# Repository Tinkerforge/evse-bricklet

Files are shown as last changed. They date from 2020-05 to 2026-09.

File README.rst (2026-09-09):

EVSE Bricklet
=============

This Bricklet together with the ESP32 Brick the NFC Bricklet and the
RS485 Bricklet form the hardware used in the WARP Charger.

See https://www.warp-charger.com/warp1.html for more details.

This repository contains the firmware source code and the hardware design
files. The documentation generator configs can be found at
https://github.com/Tinkerforge/generators

.. BEGIN WARP REPOSITORIES (managed block, generated from esp32-firmware/repo_overview.rst - do not edit by hand, run update_repo_overview.py instead)

WARP Repositories
-----------------

This is an overview of all repositories that make up the WARP Charger and
WARP Energy Manager ecosystem.

Please report **any** issue concerning WARP hard- or software in the
`esp32-firmware`_ repository, no matter which repository it originates from.

Software
~~~~~~~~

- `esp32-firmware`_ - Source code of the ESP32 firmware shared between all WARP Chargers and Energy Managers

Libraries used by the firmware:

- `tfjson`_ - SAX style JSON serializer and deserializer
- `tfnetwork`_ - Modbus TCP server and client implementation
- `tfocpp`_ - OCPP 1.6 implementation
- `tftools`_ - Miscellaneous tools and helpers

Remote access:

- `esp32-remote-access`_ - Source code of the my.warp-charger.com remote access server

Documentation, tools and integrations:

- `warp-charger`_ - Source code of (docs.)warp-charger.com and the printed manual, released firmwares, datasheets and documents, as well as some tools and hardware design files
- `api.warp-charger.com`_ - Serves APIs that are used by WARP Chargers to obtain relevant public information like day ahead prices
- `vislog.warp-charger.com`_ - Visualizes WARP Charger logs and EVSE debug protocols
- `dbus-warp-charger`_ - Integrates WARP Chargers into a Victron Energy Venus OS device (e.g. Cerbo GX)

WARP Charger Hardware
~~~~~~~~~~~~~~~~~~~~~~

WARP4 Charger
"""""""""""""

*Current charger generation.*

- `warp-esp32-ethernet-v2-brick`_ - Hardware design files of the WARP ESP32 Ethernet Brick 2.0
- `warp-esp32-ethernet-v2-co-bricklet`_ - Firmware source code of the WARP ESP32 Ethernet 2.0 Co Bricklet (co-processor)
- `evse-v4-bricklet`_ - Hardware design files of the EVSE 4.0 Bricklet (firmware shared with the EVSE 2.0 Bricklet)
- `nfc-bricklet`_ - Firmware source code and hardware design files of the NFC Bricklet

WARP3 Charger
"""""""""""""

- `warp-esp32-ethernet-brick`_ - Hardware design files of the WARP ESP32 Ethernet Brick
- `evse-v3-bricklet`_ - Hardware design files of the EVSE 3.0 Bricklet (firmware shared with the EVSE 2.0 Bricklet)
- `nfc-bricklet`_ - Firmware source code and hardware design files of the NFC Bricklet

WARP2 Charger
"""""""""""""

- `esp32-ethernet-brick`_ - Hardware design files of the ESP32 Ethernet Brick
- `evse-v2-bricklet`_ - Firmware source code and hardware design files of the EVSE 2.0 Bricklet
- `nfc-bricklet`_ - Firmware source code and hardware design files of the NFC Bricklet

WARP1 Charger
"""""""""""""

- `esp32-brick`_ - Hardware design files of the ESP32 Brick
- `evse-bricklet`_ - Firmware source code and hardware design files of the EVSE Bricklet
- `rs485-bricklet`_ - Firmware source code and hardware design files of the RS485 Bricklet

WARP Energy Manager Hardware
~~~~~~~~~~~~~~~~~~~~~~~~~~~~~~

WARP Energy Manager 2.0
"""""""""""""""""""""""

*Current energy manager generation.*

- `esp32-ethernet-brick`_ - Hardware design files of the ESP32 Ethernet Brick
- `warp-energy-manager-v2-bricklet`_ - Firmware source code and hardware design files of the WARP Energy Manager 2.0 Bricklet
- `warp-front-panel-bricklet`_ - Firmware source code and hardware design files of the WARP Front Panel Bricklet

WARP Energy Manager 1.0
"""""""""""""""""""""""

- `esp32-ethernet-brick`_ - Hardware design files of the ESP32 Ethernet Brick
- `warp-energy-manager-bricklet`_ - Firmware source code and hardware design files of the WARP Energy Manager Bricklet

Forked/patched projects
~~~~~~~~~~~~~~~~~~~~~~~~~

- `arduino-esp32`_
- `esp32-arduino-libs`_
- `WireGuard-ESP32-Arduino`_

.. Link targets: One definition per repository, keep in sync with the lists above.

.. _esp32-firmware: https://github.com/Tinkerforge/esp32-firmware
.. _tfjson: https://github.com/Tinkerforge/tfjson
.. _tfnetwork: https://github.com/Tinkerforge/tfnetwork
.. _tfocpp: https://github.com/Tinkerforge/tfocpp
.. _tftools: https://github.com/Tinkerforge/tftools
.. _esp32-remote-access: https://github.com/Tinkerforge/esp32-remote-access
.. _warp-charger: https://github.com/Tinkerforge/warp-charger
.. _api.warp-charger.com: https://github.com/Tinkerforge/api.warp-charger.com
.. _vislog.warp-charger.com: https://github.com/Tinkerforge/vislog.warp-charger.com
.. _dbus-warp-charger: https://github.com/Tinkerforge/dbus-warp-charger
.. _warp-esp32-ethernet-v2-brick: https://github.com/Tinkerforge/warp-esp32-ethernet-v2-brick
.. _warp-esp32-ethernet-v2-co-bricklet: https://github.com/Tinkerforge/warp-esp32-ethernet-v2-co-bricklet
.. _evse-v4-bricklet: https://github.com/Tinkerforge/evse-v4-bricklet
.. _nfc-bricklet: https://github.com/Tinkerforge/nfc-bricklet
.. _warp-esp32-ethernet-brick: https://github.com/Tinkerforge/warp-esp32-ethernet-brick
.. _evse-v3-bricklet: https://github.com/Tinkerforge/evse-v3-bricklet
.. _esp32-ethernet-brick: https://github.com/Tinkerforge/esp32-ethernet-brick
.. _evse-v2-bricklet: https://github.com/Tinkerforge/evse-v2-bricklet
.. _esp32-brick: https://github.com/Tinkerforge/esp32-brick
.. _evse-bricklet: https://github.com/Tinkerforge/evse-bricklet
.. _rs485-bricklet: https://github.com/Tinkerforge/rs485-bricklet
.. _warp-energy-manager-v2-bricklet: https://github.com/Tinkerforge/warp-energy-manager-v2-bricklet
.. _warp-front-panel-bricklet: https://github.com/Tinkerforge/warp-front-panel-bricklet
.. _warp-energy-manager-bricklet: https://github.com/Tinkerforge/warp-energy-manager-bricklet
.. _arduino-esp32: https://github.com/Tinkerforge/arduino-esp32
.. _esp32-arduino-libs: https://github.com/Tinkerforge/esp32-arduino-libs
.. _WireGuard-ESP32-Arduino: https://github.com/Tinkerforge/WireGuard-ESP32-Arduino

.. END WARP REPOSITORIES

Repository Content
------------------

software/:
 * examples/: Examples for all supported languages
 * build/: Compiled files
 * src/: Source code of firmware
 * Makefile: Makefile to build project

hardware/:
 * Contains KiCad project files and additionally schematics as PDF

datasheets/:
 * Contains datasheets for sensors and complex ICs that are used

Hardware
--------

The hardware is designed with the open source EDA Suite KiCad
(http://www.kicad.org). Before you are able to open the files,
you have to install the Tinkerforge kicad-libraries
(https://github.com/Tinkerforge/kicad-libraries). You can either clone
them directly in hardware/ or clone them in a separate folder and
symlink them into hardware/
(ln -s kicad_path/kicad-libraries project_path/hardware). After that you
can open the .pro file in hardware/ with KiCad and from there view and
modify the schematics and the PCB layout.

Software
--------

If you want to do your own Brick/Bricklet firmware development we highly
recommend that you use our build environment setup script and read the
tutorial (https://www.tinkerforge.com/en/doc/Tutorials/Tutorial_Build_Environment/Tutorial.html).

To compile the C code we recommend you to install the newest GNU Arm Embedded
Toolchain (https://launchpad.net/gcc-arm-embedded/+download).
You also need to install bricklib2 (https://github.com/Tinkerforge/bricklib2).

You can either clone it directly in software/src/ or clone it in a
separate folder and symlink it into software/src/
(ln -s bricklib_path/bricklib2 project_path/software/src/). Finally make sure to
have CMake installed (http://www.cmake.org/cmake/resources/software.html).

After that you can build the firmware by invoking make in software/.
The firmware (.zbin) can then be found in software/build/ and uploaded
with brickv (click button "Flashing" on start screen).

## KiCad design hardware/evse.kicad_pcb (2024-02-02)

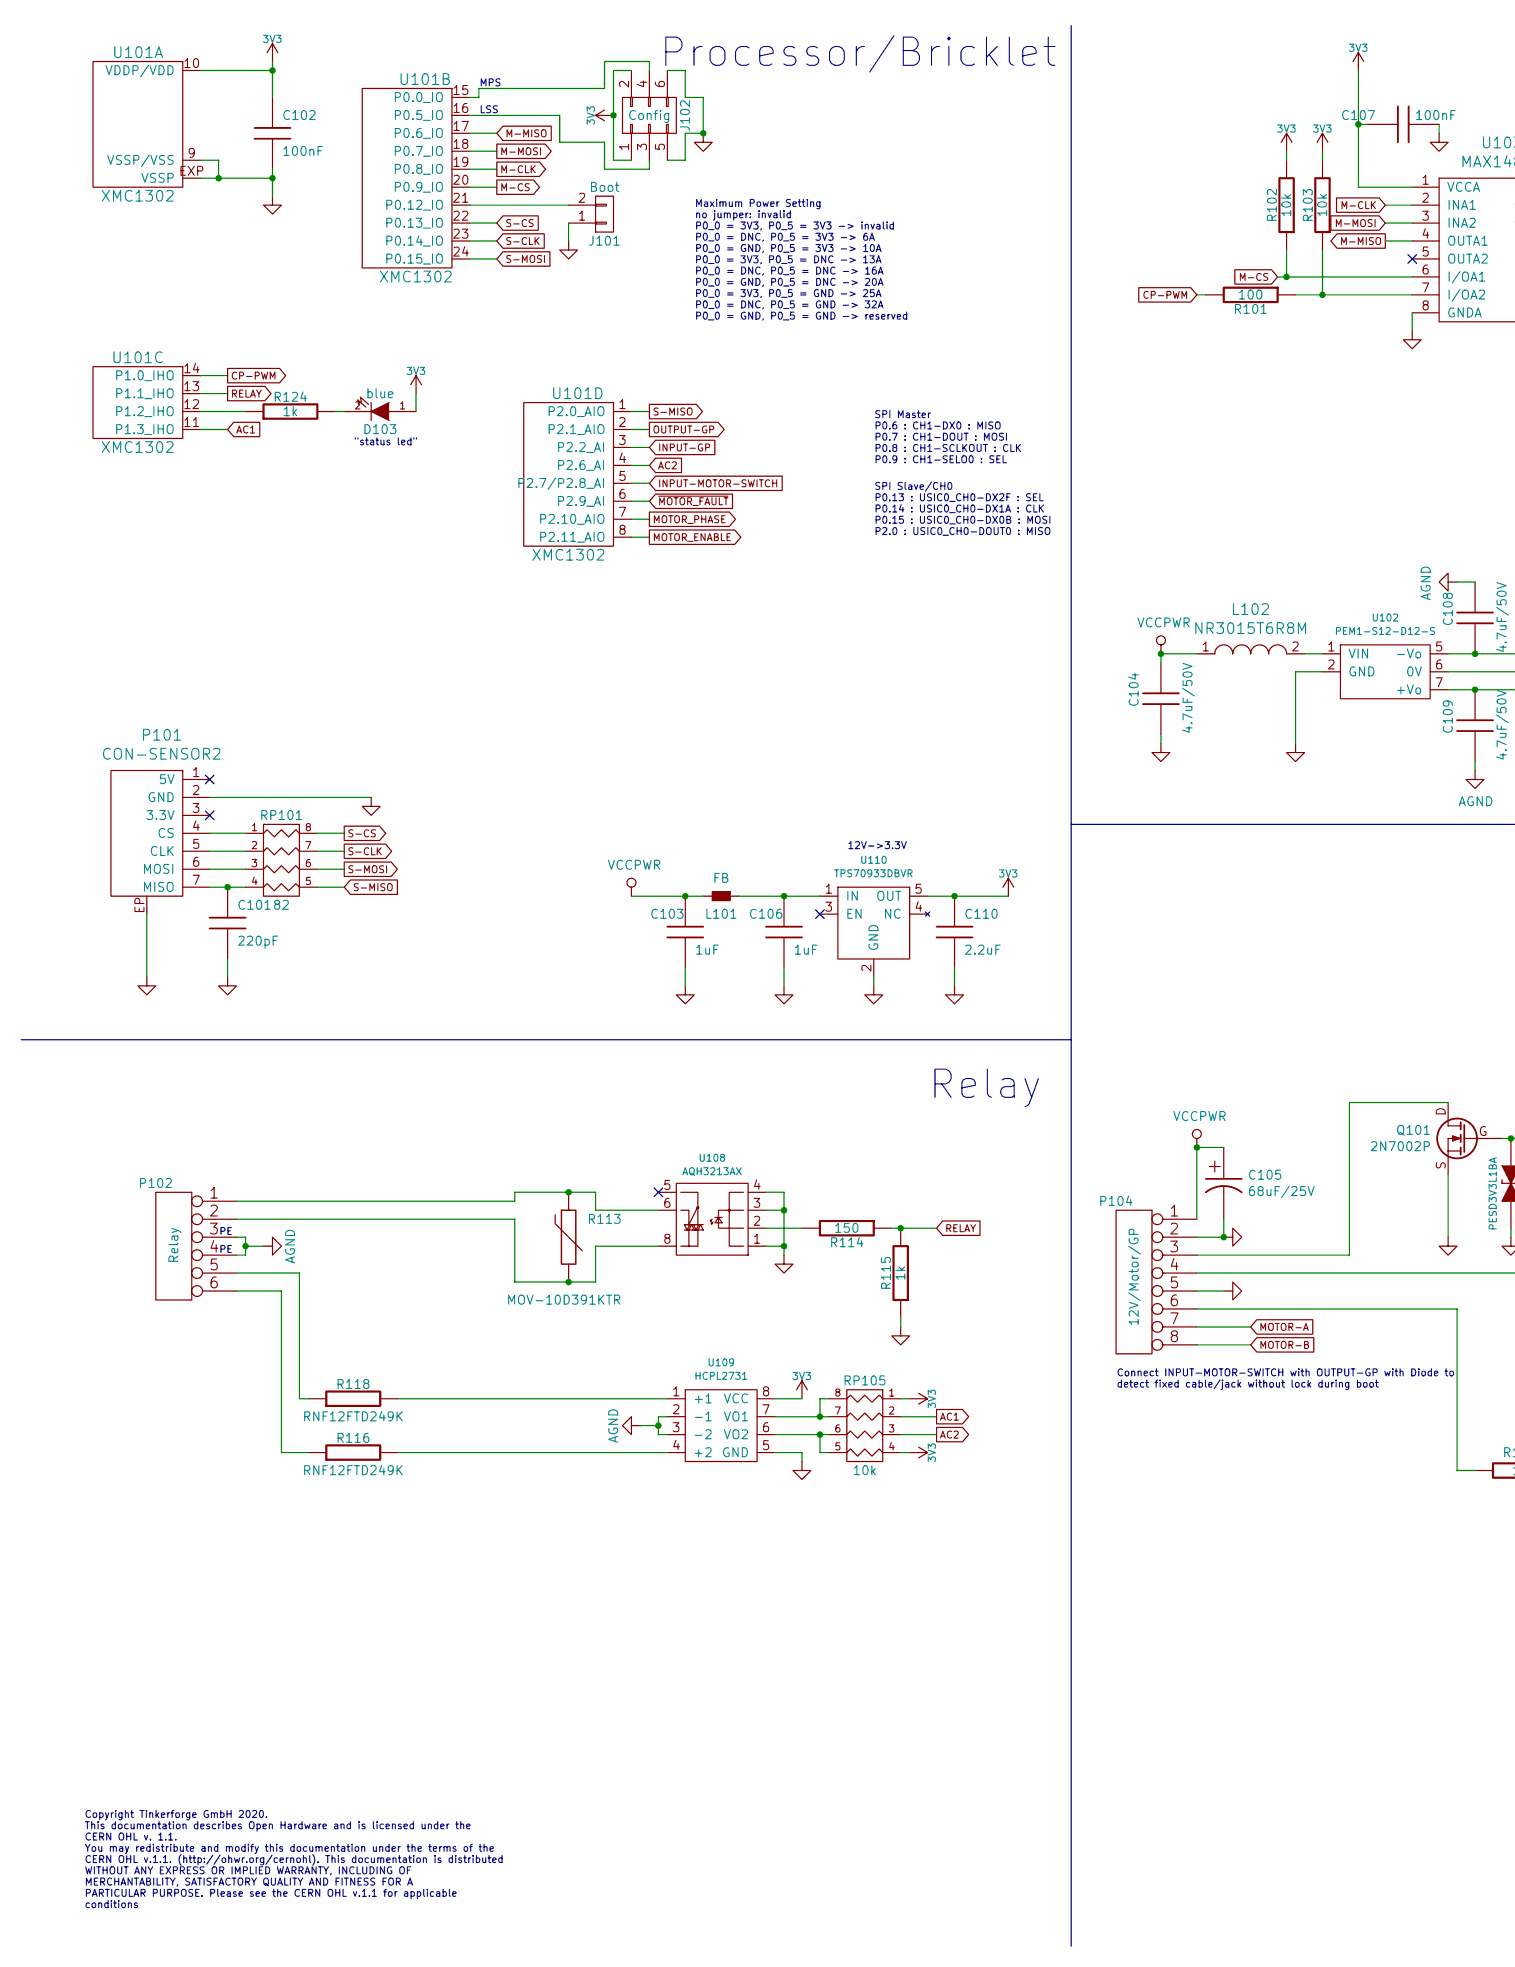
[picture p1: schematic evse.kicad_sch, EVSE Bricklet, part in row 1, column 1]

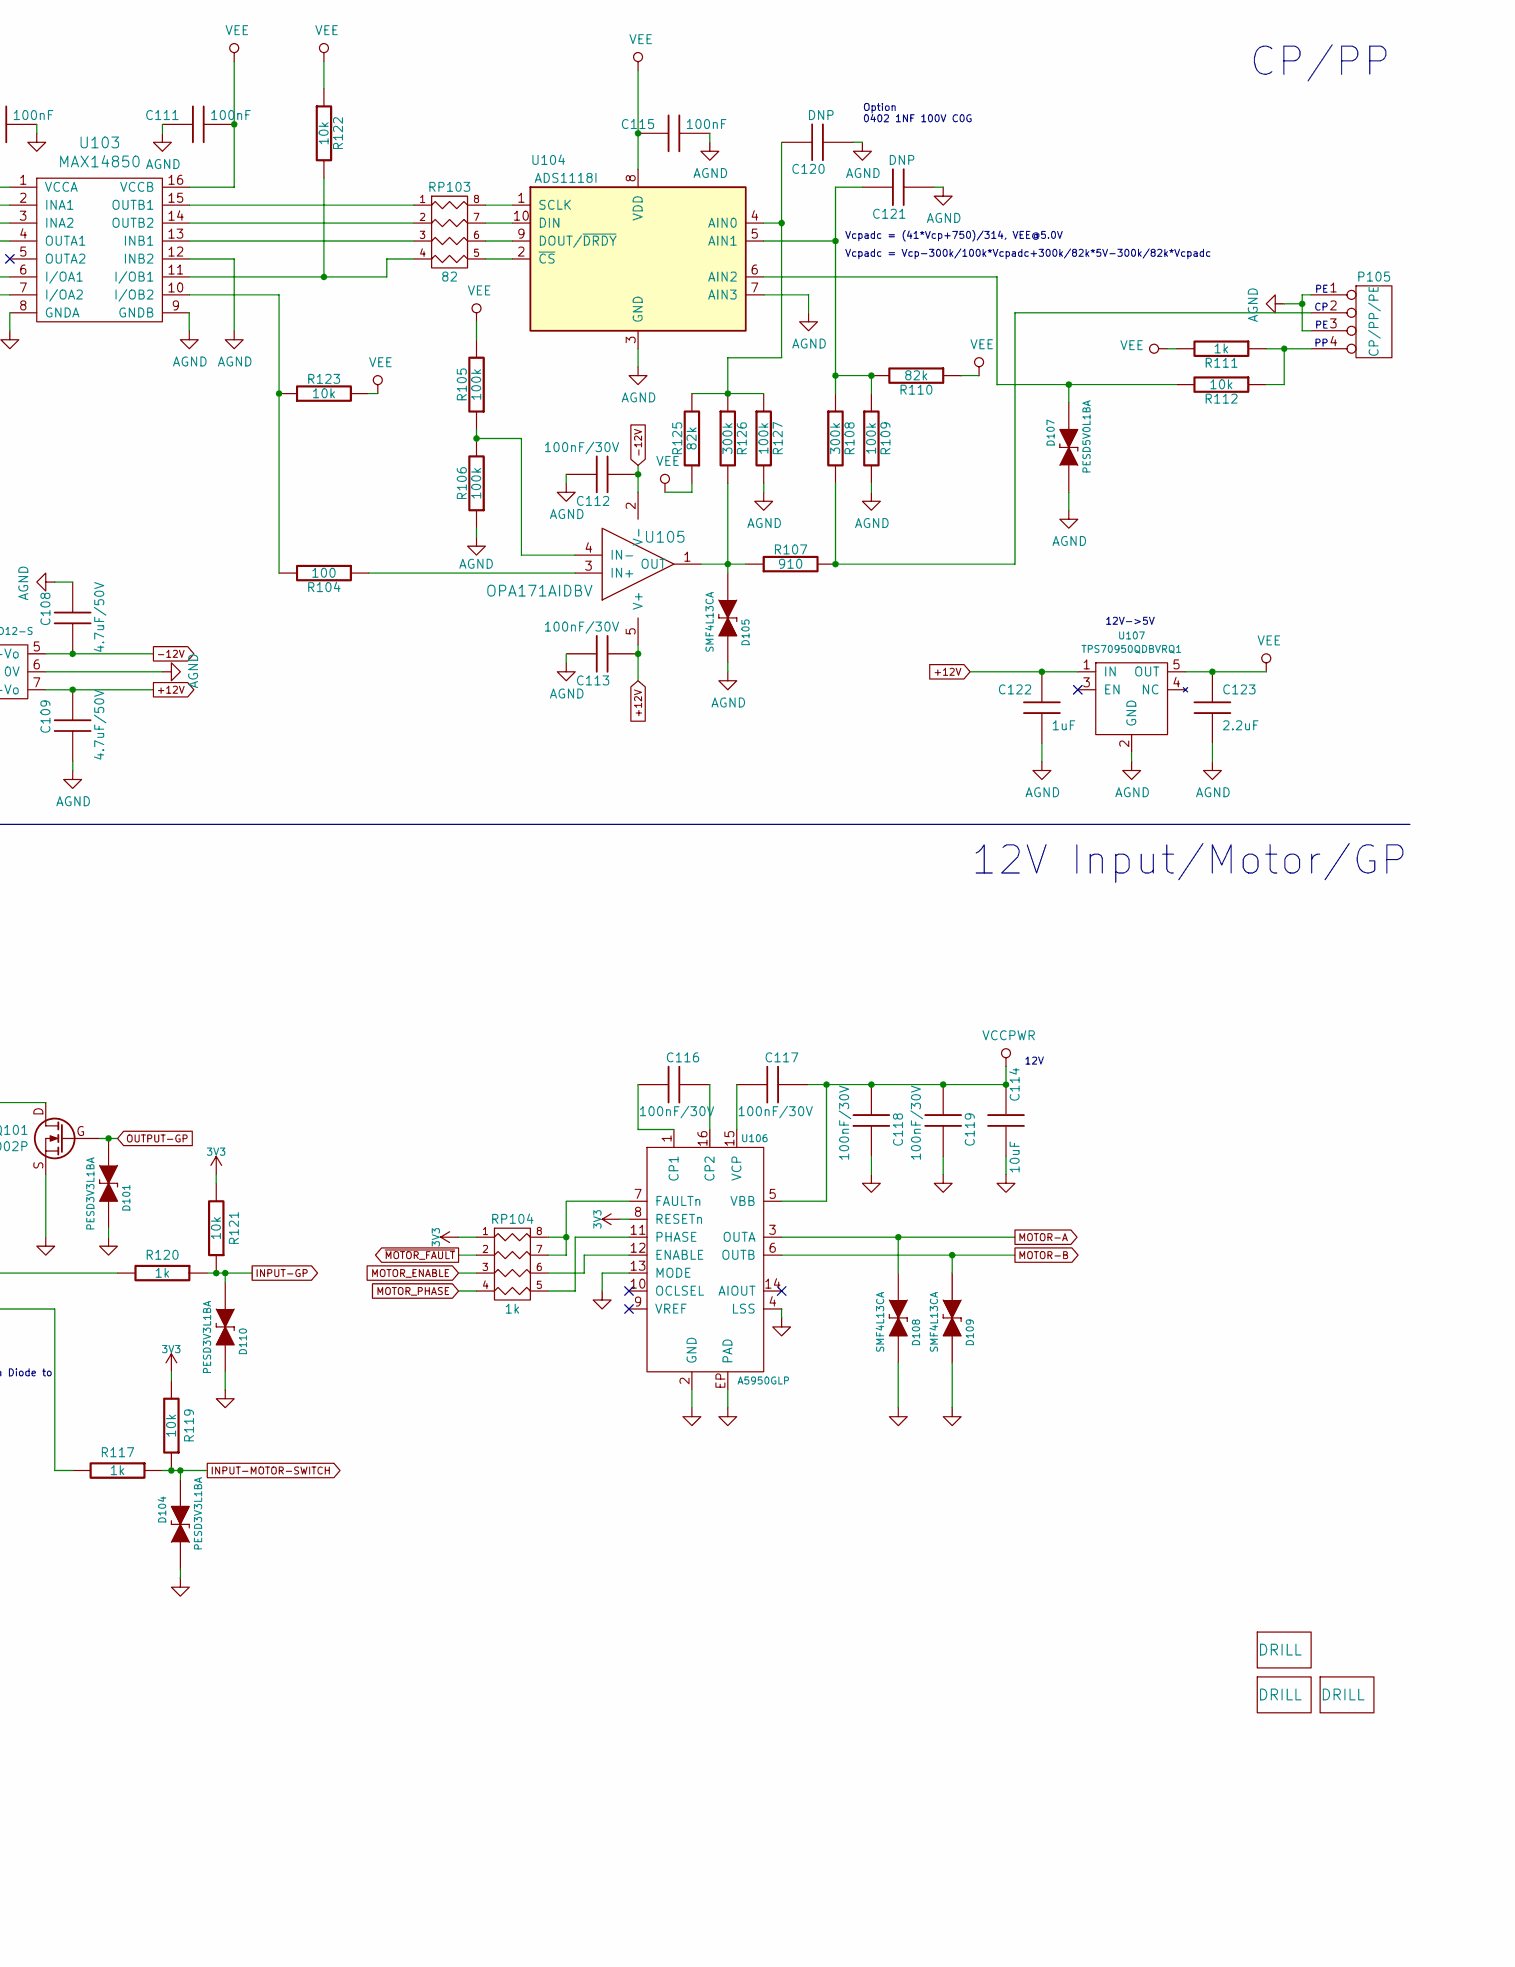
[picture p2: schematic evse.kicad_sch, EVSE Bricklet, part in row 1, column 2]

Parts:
A101, A102, A103: DRILL; DRILL_NP
C101: 220pF; C0402F
C102, C107, C111, C115: 100nF; C0603F
C103, C106, C122: 1uF; C0603F
C104, C108, C109: 4.7uF/50V; C1206
C105: 68uF/25V; ELKO_63
C110, C123: 2.2uF; C0603F
C112, C113, C116, C117, C118, C119: 100nF/30V; C0603F
C114: 10uF; C1206
C120, C121: DNP; C0402F
D101, D104, D110: ‎PESD3V3L1BA; SOD-323
D103: blue; D0603F
D105, D108, D109: SMF4L13CA; SOD-123FL
D107: ‎PESD5V0L1BA; SOD-323
J101: Boot; SolderJumper
J102: Config; Pin_Header_Straight_2x03_127
L101: FB; R0603F
L102: NR3015T6R8M; NR3030
P101: CON-SENSOR2; CON-SENSOR2_180
P102: Relay; OQ_6P_Vertical
P104: 12V/Motor/GP; OQ_8P_Vertical
P105: CP/PP/PE; OQ_4P_Vertical
Q101: 2N7002P; SOT23GDS
R101, R104: 100; R0603F
R102, R103, R112, R119, R121, R122, R123: 10k; R0603F
R105, R106, R109, R127: 100k; R0603F
R107: 910; R0603F
R108, R126: 300k; R0603F
R110, R125: 82k; R0603F
R111, R115, R117, R120, R124: 1k; R0603F
R113: MOV-10D391KTR; VAR_10mm
R114: 150; R0603F
R116, R118: RNF12FTD249K; RNF12
RP101, RP103: 82; 4X0402
RP104: 1k; 4X0603
RP105: 10k; 4X0603
U101: XMC1302; QFN24-4x4mm-0.5mm
U102: PEM1-S12-D12-S; PEM1S
U103: MAX14850; SOIC16
U104: ADS1118I; VSSOP10
U105: OPA171AIDBV; SOT23-5
U106: A5950GLP; TSSOP16_EP
U107: TPS70950QDBVRQ1; SOT23-5
U108: AQH3213AX; AQ-H
U109: HCPL2731; DIP-8
U110: TPS70933DBVR; SOT23-5

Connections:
3V3: C102.1, C107.1, C110.1, D103.1 (A), J102.1, J102.2, R102.2, R103.2, R119.2, R121.2, RP104.1, RP105.1, RP105.4, U101.10 (VDDP/VDD), U103.1 (VCCA), U106.8 (RESETn), U109.8 (VCC), U110.5 (OUT)
+12V: C109.1, C113.2, C122.1, U102.7 (+Vo), U105.5 (V+), U107.1 (IN)
-12V: C108.2, C112.2, U102.5 (-Vo), U105.2 (V-)
AC1: RP105.2, U101.11 (P1.3_IHO)
AC2: RP105.3, U101.4 (P2.6_AI)
AGND: C108.1, C109.2, C111.1, C112.1, C113.1, C115.2, C120.2, C121.2, C122.2, C123.2, D105.2 (K), D107.1 (A), P102.3, P102.4, P105.1, P105.3, R106.1, R109.2, R127.2, U102.6 (0V), U103.9 (GNDB), U103.12 (INB2), U104.3 (GND), U104.7 (AIN3), U107.2 (GND), U109.2 (-1), U109.3 (-2)
CP-PWM: R101.2, U101.14 (P1.0_IHO)
GND: C101.2, C102.2, C103.2, C104.2, C105.2, C106.2, C107.2, C110.2, C114.2, C118.1, C119.1, D101.2 (K), D104.1 (A), D108.2 (K), D109.2 (K), D110.2 (K), J101.1, J102.5, J102.6, P101.2 (GND), P101.EP, P104.2, P104.5, Q101.S, R115.1, U101.9 (VSSP/VSS), U101.EXP (VSSP), U102.2 (GND), U103.8 (GNDA), U106.2 (GND), U106.4 (LSS), U106.13 (MODE), U106.EP (PAD), U108.1, U108.3, U108.4, U109.5 (GND), U110.2 (GND)
INPUT-GP: D110.1 (A), R120.1, R121.1, U101.3 (P2.2_AI)
INPUT-MOTOR-SWITCH: D104.2 (K), R117.1, R119.1, U101.5 (P2.7/P2.8_AI)
M-CLK: U101.19 (P0.8_IO), U103.2 (INA1)
M-CS: R102.1, U101.20 (P0.9_IO), U103.6 (I/OA1)
M-MISO: U101.17 (P0.6_IO), U103.4 (OUTA1)
M-MOSI: U101.18 (P0.7_IO), U103.3 (INA2)
MOTOR-A: D108.1 (A), P104.7, U106.3 (OUTA)
MOTOR-B: D109.1 (A), P104.8, U106.6 (OUTB)
MOTOR_ENABLE: RP104.3, U101.8 (P2.11_AIO)
MOTOR_PHASE: RP104.4, U101.7 (P2.10_AIO)
unnamed: C101.1, P101.7 (MISO), RP101.4
unnamed: C106.1, L101.1, U110.1 (IN)
unnamed: C116.1, U106.16 (CP2)
unnamed: C116.2, U106.1 (CP1)
unnamed: C117.2, U106.15 (VCP)
unnamed: C120.1, R125.2, R126.1, R127.1, U104.4 (AIN0)
unnamed: C121.1, R108.1, R109.1, R110.2, U104.5 (AIN1)
unnamed: D103.2 (K), R124.2
unnamed: D105.1 (A), R107.1, R126.2, U105.1 (OUT)
unnamed: D107.2 (K), R112.2, U104.6 (AIN2)
unnamed: J101.2, U101.21 (P0.12_IO)
unnamed: J102.3, U101.16 (P0.5_IO)
unnamed: J102.4, U101.15 (P0.0_IO)
unnamed: L102.2, U102.1 (VIN)
unnamed: P101.4 (CS), RP101.1
unnamed: P101.5 (CLK), RP101.2
unnamed: P101.6 (MOSI), RP101.3
unnamed: P102.1, R113.1, U108.6
unnamed: P102.2, R113.2, U108.8
unnamed: P102.5, R118.1
unnamed: P102.6, R116.1
unnamed: P104.3, Q101.D
unnamed: P104.4, R120.2
unnamed: P104.6, R117.2
unnamed: P105.2, R107.2, R108.2
unnamed: P105.4, R111.1, R112.1
unnamed: R101.1, R103.1, U103.7 (I/OA2)
unnamed: R104.1, U105.3 (IN+)
unnamed: R104.2, R123.1, U103.10 (I/OB2)
unnamed: R105.1, R106.2, U105.4 (IN-)
unnamed: R114.2, U108.2
unnamed: R116.2, U109.4 (+2)
unnamed: R118.2, U109.1 (+1)
unnamed: R122.2, RP103.4, U103.11 (I/OB1)
unnamed: R124.1, U101.12 (P1.2_IHO)
unnamed: RP103.1, U103.15 (OUTB1)
unnamed: RP103.2, U103.14 (OUTB2)
unnamed: RP103.3, U103.13 (INB1)
unnamed: RP103.5 (R4), U104.2 (~CS)
unnamed: RP103.6 (R3), U104.9 (DOUT/~DRDY)
unnamed: RP103.7 (R2), U104.10 (DIN)
unnamed: RP103.8 (R1), U104.1 (SCLK)
unnamed: RP104.5 (R4), U106.11 (PHASE)
unnamed: RP104.6 (R3), U106.12 (ENABLE)
unnamed: RP104.7 (R2), RP104.8 (R1), U106.7 (FAULTn)
unnamed: RP105.5 (R4), RP105.6 (R3), U109.6 (VO2)
unnamed: RP105.7 (R2), RP105.8 (R1), U109.7 (VO1)
OUTPUT-GP: D101.1 (A), Q101.G, U101.2 (P2.1_AIO)
RELAY: R114.1, R115.2, U101.13 (P1.1_IHO)
S-CLK: RP101.7 (R2), U101.23 (P0.14_IO)
S-CS: RP101.8 (R1), U101.22 (P0.13_IO)
S-MISO: RP101.5 (R4), U101.1 (P2.0_AIO)
S-MOSI: RP101.6 (R3), U101.24 (P0.15_IO)
VCC: C103.1, C104.1, C105.1, C114.1, C117.1, C118.2, C119.2, L101.2, L102.1, P104.1, U106.5 (VBB)
VEE: C111.2, C115.1, C123.1, R105.2, R110.1, R111.2, R122.1, R123.2, R125.1, U103.16 (VCCB), U104.8 (VDD), U107.5 (OUT)
~MOTOR_FAULT: RP104.2, U101.6 (P2.9_AI)

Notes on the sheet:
Relay
Vcpadc = Vcp-300k/100k*Vcpadc+300k/82k*5V-300k/82k*Vcpadc
12V
Processor/Bricklet
LSS
"status led"
SPI Slave/CH0 P0.13 : USIC0_CH0-DX2F : SEL P0.14 : USIC0_CH0-DX1A : CLK P0.15 : USIC0_CH0-DX0B : MOSI P2.0 : USIC0_CH0-DOUT0 : MISO
Maximum Power Setting no jumper: invalid P0_0 = 3V3, P0_5 = 3V3 -> invalid P0_0 = DNC, P0_5 = 3V3 -> 6A P0_0 = GND, P0_5 = 3V3 -> 10A P0_0 = 3V3, P0_5 = DNC -> 13A P0_0 = DNC, P0_5 = DNC -> 16A P0_0 = GND, P0_5 = DNC -> 20A P0_0 = 3V3, P0_5 = GND -> 25A P0_0 = DNC, P0_5 = GND -> 32A P0_0 = GND, P0_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
CP/PP
MPS
12V Input/Motor/GP
Option 0402 1NF 100V C0G
12V->5V
Copyright Tinkerforge GmbH 2020. This documentation describes Open Hardware and is licensed under the CERN OHL v. 1.1. You may redistribute and modify this documentation under the terms of the CERN OHL v.1.1. (http://ohwr.org/cernohl). This documentation is distributed WITHOUT ANY EXPRESS OR IMPLIE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
Connect INPUT-MOTOR-SWITCH with OUTPUT-GP with Diode to detect fixed cable/jack without lock during boot
12V->3.3V
Vcpadc = (41*Vcp+750)/314, VEE@5.0V
SPI Master P0.6 : CH1-DX0 : MISO P0.7 : CH1-DOUT : MOSI P0.8 : CH1-SCLKOUT : CLK P0.9 : CH1-SELO0 : SEL

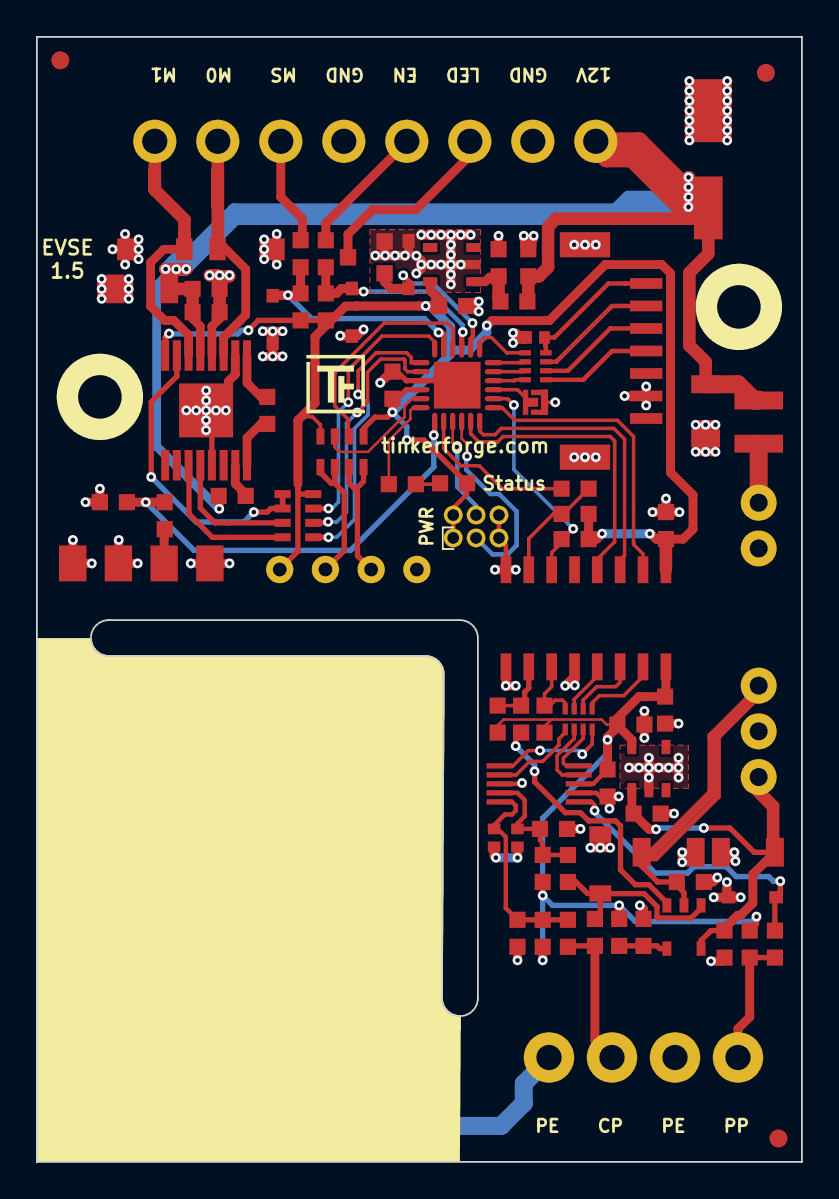
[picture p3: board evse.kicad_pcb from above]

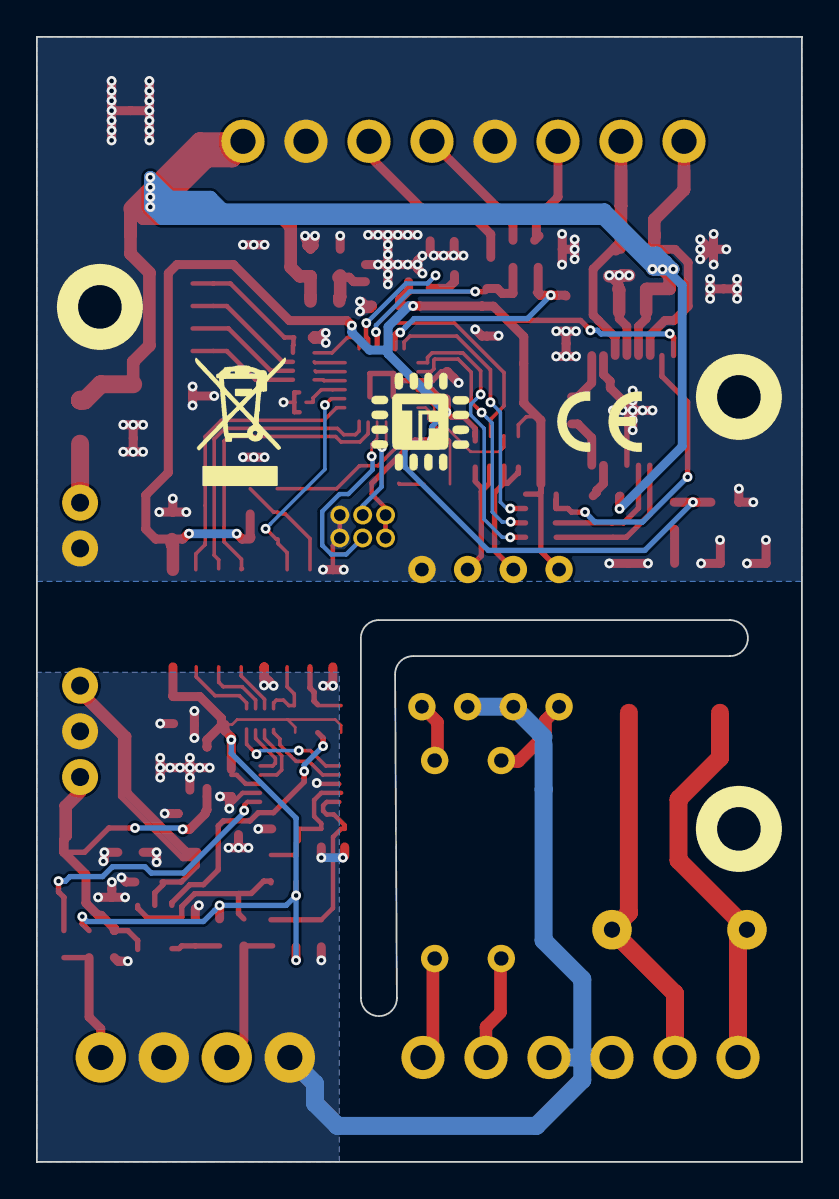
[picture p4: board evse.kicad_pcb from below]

Board: 2 copper layers, 42.5 x 62.5 mm, 90 parts (2 on the bottom side), 74 nets.

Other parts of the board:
Fiducial_Mark: VAL**; Fiducial_Mark
Fiducial_Mark#2, Fiducial_Mark#3, Fiducial_Mark#4: VAL**; Fiducial_Mark
VAL: CE_5mm
VAL#2: WEEE_7mm

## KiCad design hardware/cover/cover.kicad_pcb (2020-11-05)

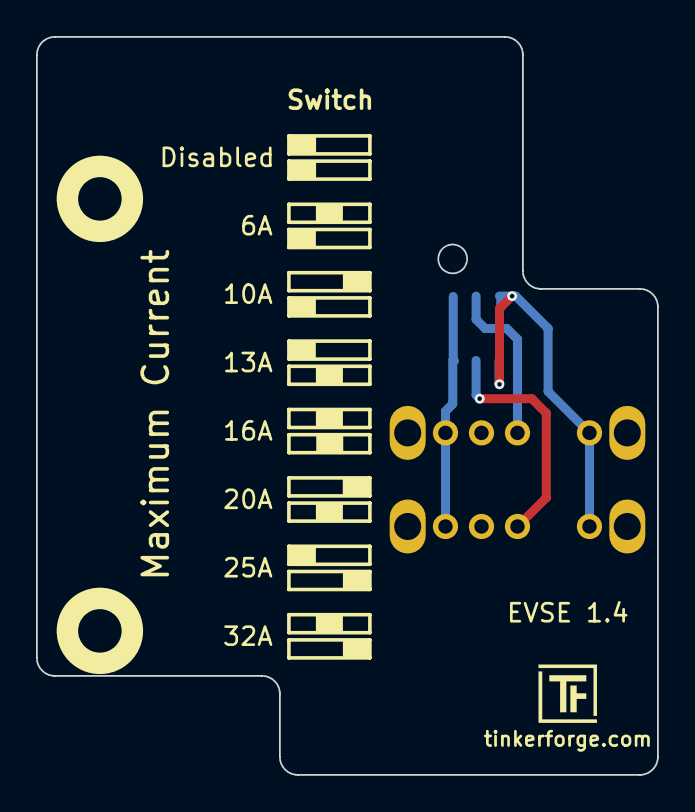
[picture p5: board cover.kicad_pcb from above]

Board: 2 copper layers, 34.5 x 41.0 mm, 5 parts (1 on the bottom side), 4 nets.

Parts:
A101, A103: DRILL; DRILL_NP
P101: CONN_02X03; Pin_Header_Straight_Female_2x03_127
SW101, SW102: OS103011MS8QP1

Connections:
3V3: P101.1, P101.2, SW101.4, SW102.4
GND: P101.5, P101.6, SW101.1, SW102.1
unnamed: P101.3, SW102.2
unnamed: P101.4, SW101.2

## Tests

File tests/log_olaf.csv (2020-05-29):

Time | IEC61851 State | LED State | Resistance CP/PE | Resistance PP/PE | CP PWM Duty Cycle | Contactor State | Contactor Check Error | GPIO Enable | GPIO LED | GPIO Motor Switch | Lock State | Jumper Configuration | Lock Switch
15907551989 | 2 | 3 | 899 | 680 | 266 | 3 | 0 | True | True | False | True | 3 | 3
15907551991 | 2 | 3 | 898 | 680 | 266 | 3 | 0 | True | True | False | True | 3 | 3
15907551993 | 2 | 3 | 898 | 680 | 266 | 3 | 0 | True | True | False | True | 3 | 3
15907551995 | 2 | 3 | 898 | 680 | 266 | 3 | 0 | True | True | False | True | 3 | 3
15907551997 | 2 | 3 | 900 | 680 | 266 | 3 | 0 | True | True | False | True | 3 | 3
15907551999 | 2 | 3 | 905 | 680 | 266 | 3 | 0 | True | False | True | True | 3 | 3
15907552001 | 2 | 3 | 905 | 680 | 266 | 3 | 0 | True | False | True | True | 3 | 3
15907552003 | 2 | 3 | 913 | 680 | 266 | 3 | 0 | True | False | True | True | 3 | 3
15907552005 | 2 | 3 | 919 | 680 | 266 | 3 | 0 | True | True | False | True | 3 | 3
15907552007 | 2 | 3 | 923 | 680 | 266 | 3 | 0 | True | True | False | True | 3 | 3
15907552009 | 2 | 3 | 922 | 680 | 266 | 3 | 0 | True | True | False | True | 3 | 3
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

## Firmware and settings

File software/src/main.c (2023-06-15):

/* evse-bricklet
 * Copyright (C) 2020-2022 Olaf Lüke <olaf@tinkerforge.com>
 *
 * main.c: Initialization for EVSE Bricklet
 *
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
 * You should have received a copy of the GNU Lesser General Public
 * License along with this library; if not, write to the
 * Free Software Foundation, Inc., 59 Temple Place - Suite 330,
 * Boston, MA 02111-1307, USA.
 */

#include <stdio.h>
#include <stdbool.h>

#include "configs/config.h"

#include "bricklib2/bootloader/bootloader.h"
#include "bricklib2/hal/system_timer/system_timer.h"
#include "bricklib2/logging/logging.h"
#include "bricklib2/warp/contactor_check.h"
#include "communication.h"

#include "evse.h"
#include "ads1118.h"
#include "iec61851.h"
#include "lock.h"
#include "led.h"
#include "button.h"
#include "charging_slot.h"

int main(void) {
	logging_init();
	logd("Start EVSE Bricklet\n\r");

	communication_init();
	evse_init();
	charging_slot_init();
	ads1118_init();
	iec61851_init();
	lock_init();
	contactor_check_init();
	led_init();
	button_init();

	while(true) {
		bootloader_tick();
		communication_tick();
		evse_tick();
		ads1118_tick();
//		lock_tick();
		contactor_check_tick();
		led_tick();
		button_tick();
		charging_slot_tick();
	}
}

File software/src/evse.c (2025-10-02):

/* evse-bricklet
 * Copyright (C) 2020-2022 Olaf Lüke <olaf@tinkerforge.com>
 *
 * evse.c: EVSE implementation
 *
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
 * You should have received a copy of the GNU Lesser General Public
 * License along with this library; if not, write to the
 * Free Software Foundation, Inc., 59 Temple Place - Suite 330,
 * Boston, MA 02111-1307, USA.
 */

#include "evse.h"

#include <float.h>

#include "configs/config_evse.h"
#include "bricklib2/hal/ccu4_pwm/ccu4_pwm.h"
#include "bricklib2/hal/system_timer/system_timer.h"
#include "bricklib2/logging/logging.h"
#include "bricklib2/utility/util_definitions.h"
#include "bricklib2/bootloader/bootloader.h"
#include "bricklib2/warp/contactor_check.h"

#include "ads1118.h"
#include "iec61851.h"
#include "lock.h"
#include "led.h"
#include "communication.h"
#include "charging_slot.h"

#define EVSE_RELAY_MONOFLOP_TIME 10000 // 10 seconds

EVSE evse;

void evse_set_output(const uint16_t cp_duty_cycle, const bool contactor) {
	evse_set_cp_duty_cycle(cp_duty_cycle);

	// If the contactor is to be enabled and the lock is currently
	// not completely closed, we start the locking procedure and return.
	// The contactor will only be enabled after the lock is closed.
#if 0
	if(contactor) {
		if(lock_get_state() != LOCK_STATE_CLOSE) {
			lock_set_locked(true);
			return;
		}
	}
#endif

	if(((bool)XMC_GPIO_GetInput(EVSE_RELAY_PIN)) != contactor) {
		if(((cp_duty_cycle == 0) || (cp_duty_cycle == 1000)) && (!contactor)) {
			// If the duty cycle is set to either 0% or 100% PWM and the contactor is supposed to be turned off,
			// it is possible that the WARP Charger wants to turn off the charging session while the car
			// still wants to charge. In this case we wait until the car actually stops charging and
			// changes the resistance back to 2700 ohm before we turn the contactor off.
			// This assures that the contactor is not switched under load.
			//
			// NOTE: In case of an emergency (for example a dc fault detection) the contactor is of course switched off
			//       immediately and directly in the fault detection code without any regard to charging-state,
			//       PWM value, resistance or similar.
			//       This function is only called in non-emergency cases.

			if(ads1118.cp_pe_resistance <= IEC61851_CP_RESISTANCE_STATE_B) {
				if(evse.contactor_turn_off_time == 0) {
					evse.contactor_turn_off_time = system_timer_get_ms();
					return;
				} else if(system_timer_is_time_elapsed_ms(evse.contactor_turn_off_time, 3*1000)) {
					// The car has to respond within 3 seconds (see IEC 61851-1 standard table A.6 sequence 10.1),
					// thus after 3 seconds we turn the contactor off, even if the car has not yet responded yet.
					// In this case there may be some kind of communication error between wallbox and car and it
					// is better to turn the contactor off, even if still under load.
					evse.contactor_turn_off_time = 0;
				} else {
					return;
				}
			} else {
				evse.contactor_turn_off_time = 0;
			}
		}


		// Ignore all ADC measurements for a while if the contactor is
		// switched on or off, to be sure that the resulting EMI spike does
		// not give us a wrong measurement.
		ads1118.cp_invalid_counter = MAX(4, ads1118.cp_invalid_counter);
		ads1118.pp_invalid_counter = MAX(4, ads1118.pp_invalid_counter);

		// Also ignore contactor check for a while when contactor changes state
		contactor_check.invalid_counter = MAX(5, contactor_check.invalid_counter);

		if(contactor) {
			XMC_GPIO_SetOutputHigh(EVSE_RELAY_PIN);
		} else {
			XMC_GPIO_SetOutputLow(EVSE_RELAY_PIN);
		}
	}

#if 0
	if(!contactor) {
		if(lock_get_state() != LOCK_STATE_OPEN) {
			lock_set_locked(false);
		}
	}
#endif
}

// Check for presence of lock motor switch by checking between LED output and switch
void evse_init_lock_switch(void) {
// Remove lock switch support for now, it is not used by any WARP Charger
#if 0
#if LOGGING_LEVEL == LOGGING_NONE
	// Test if there is a connection between the GP output and the motor lock switch input
	// If there is, it means that the EVSE is configured to run without a motor lock switch input
	XMC_GPIO_SetOutputHigh(EVSE_OUTPUT_GP_PIN);
	system_timer_sleep_ms(50);
	const bool test1 = !XMC_GPIO_GetInput(EVSE_MOTOR_INPUT_SWITCH_PIN);

	XMC_GPIO_SetOutputLow(EVSE_OUTPUT_GP_PIN);
	system_timer_sleep_ms(50);
	const bool test2 = XMC_GPIO_GetInput(EVSE_MOTOR_INPUT_SWITCH_PIN);

	evse.has_lock_switch = !(test1 && test2);
#else
	evse.has_lock_switch = false;
#endif
#endif
	evse.has_lock_switch = false;
}

// Check pin header for max current
void evse_init_jumper(void) {
	const XMC_GPIO_CONFIG_t pin_config_input_tristate = {
		.mode             = XMC_GPIO_MODE_INPUT_TRISTATE,
		.input_hysteresis = XMC_GPIO_INPUT_HYSTERESIS_STANDARD
	};

	const XMC_GPIO_CONFIG_t pin_config_input_pullup = {
		.mode             = XMC_GPIO_MODE_INPUT_PULL_UP,
		.input_hysteresis = XMC_GPIO_INPUT_HYSTERESIS_STANDARD
	};

	const XMC_GPIO_CONFIG_t pin_config_input_pulldown = {
		.mode             = XMC_GPIO_MODE_INPUT_PULL_DOWN,
		.input_hysteresis = XMC_GPIO_INPUT_HYSTERESIS_STANDARD
	};

	XMC_GPIO_Init(EVSE_CONFIG_JUMPER_PIN0, &pin_config_input_pullup);
	XMC_GPIO_Init(EVSE_CONFIG_JUMPER_PIN1, &pin_config_input_pullup);
	system_timer_sleep_ms(50);
	bool pin0_pu = XMC_GPIO_GetInput(EVSE_CONFIG_JUMPER_PIN0);
	bool pin1_pu = XMC_GPIO_GetInput(EVSE_CONFIG_JUMPER_PIN1);

	XMC_GPIO_Init(EVSE_CONFIG_JUMPER_PIN0, &pin_config_input_pulldown);
	XMC_GPIO_Init(EVSE_CONFIG_JUMPER_PIN1, &pin_config_input_pulldown);
	system_timer_sleep_ms(50);
	bool pin0_pd = XMC_GPIO_GetInput(EVSE_CONFIG_JUMPER_PIN0);
	bool pin1_pd = XMC_GPIO_GetInput(EVSE_CONFIG_JUMPER_PIN1);

	XMC_GPIO_Init(EVSE_CONFIG_JUMPER_PIN0, &pin_config_input_tristate);
	XMC_GPIO_Init(EVSE_CONFIG_JUMPER_PIN1, &pin_config_input_tristate);

	// Differentiate between high, low and open
	char pin0 = 'x';
	if(pin0_pu && !pin0_pd) {
		pin0 = 'o';
	} else if(pin0_pu && pin0_pd) {
		pin0 = 'h';
	} else if(!pin0_pu && !pin0_pd) {
		pin0 = 'l';
	}

	char pin1 = 'x';
	if(pin1_pu && !pin1_pd) {
		pin1 = 'o';
	} else if(pin1_pu && pin1_pd) {
		pin1 = 'h';
	} else if(!pin1_pu && !pin1_pd) {
		pin1 = 'l';
	}
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

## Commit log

2020-04-03 version 1.0
    [evse.kicad_pcb, evse.sch]
2020-04-03 specify 3.3V TVS Diodes
    [evse.kicad_pcb, evse.sch]
2020-04-06 ordered prototype
    [evse.kicad_pcb, evse.sch]
2020-04-06 start version 1.1
    * fix connector orientation (rotate by 180 degree)
    [evse.kicad_pcb, evse.sch]
2020-04-16 fix bottom logo positions
    [evse.kicad_pcb]
2020-04-16 fixed typo
    [evse.kicad_pcb]
2020-04-17 changed cap value
    [evse.kicad_pcb, evse.sch]
2020-04-20 Add initial test firmware
    [cmake_config_custom.txt]
2020-04-21 specify resistor
    [evse.kicad_pcb, evse.sch]
2020-04-21 fix m-cs and pwm signal shift
    [evse.kicad_pcb, evse.sch]
2020-04-21 thermal improvement
    [evse.kicad_pcb, evse.sch]
2020-04-21 change p105 pinout, add description text
    [evse.kicad_pcb, evse.sch]
2020-04-21 change mounting hole positions
    [evse.kicad_pcb]
2020-04-21 change fiducial positons
    [evse.kicad_pcb]
2020-04-21 add some artwork, add missing pullup resistors for pwm and cs
    [evse.kicad_pcb, evse.sch]
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2020-04-21 change relay and led pins, fix relay series resistor
    [evse.kicad_pcb, evse.sch]
2020-04-21 small routing improvements
    [evse.kicad_pcb]
2020-04-22 fix tvs/zener diodes, fix pp description
    [evse.kicad_pcb, evse.sch]
2020-04-22 Add stub for ADS1118 16-Bit SPI ADC driver
2020-04-22 fix led colors and description
    [evse.kicad_pcb, evse.sch]
2020-04-27 add version 1.2:
    remove error led
    add maximum power jumper
    [evse.kicad_pcb, evse.sch]
2020-04-29 change to xmc1302
    [evse.kicad_pcb, evse.sch]
2020-04-30 add version 1.3
    * add external output for led control
    * remove internal charge led
    * add cutout
    * change pin mappings
    * change pin silkscreen text
    [evse.kicad_pcb, evse.sch]
2020-05-15 Update pinout to new hardware version, improve debug
    [cmake_config_custom.txt]
2020-05-19 start version 1.4, change configuration header
    [evse.kicad_pcb, evse.sch]
2020-05-19 change current setting documentation
    [evse.sch]
2020-05-19 ordered version
    [evse.kicad_pcb, evse.sch]
2020-05-20 Add support for LED, button and jumper configuration
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2020-05-29 Add EVSE logger and two example logs
    [log_olaf.csv]
2020-07-09 Use UINT32_T for moving average and a max resistance of 0xFFFF
    With this we have enough room to do the moving average without overflow
2020-08-10 Button logic changed from active high to active low
2020-09-25 Add calibration API
    TODO: Actual calibration still missing
    [ads1118.c, ads1118.h, communication.c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]
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2020-09-29 add formula
    [evse.sch]
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2020-10-07 mark diode as DNP
    [evse.kicad_pcb, evse.sch]
2020-10-09 Implement new calibration method
    We now calibrate the "max voltage" as well as the
    offset to the absolute value of the "min voltage"
    by external measurements.
    This makes the resistance measurement very precise now
    (maximum error of +-1.5% now in my tests).
    [ads1118.c, ads1118.h, communication.c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]
2020-10-14 updated vertical OQ connectors with new F.Fab layer
    [evse.kicad_pcb]
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2020-10-15 add cover pcb
    [cover.kicad_pcb, cover.sch]
2020-10-26 decrease outline dimensions
    [cover.kicad_pcb]
2020-10-30 Add LED error states
    [evse.c, evse.h, iec61851.c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]
2020-10-30 Handle LED state changes when button was pressed properly
2020-11-05 change cover to two single switch design, change current setting!!!!
    [cover.kicad_pcb, cover.sch, evse.sch]
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2020-11-16 fix comments
    [cover.sch, evse.sch]
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2020-12-03 Switch between normal loop and fast loop depending on IEC61851 state.
    When we are in state C, the standard says that we have to turn the
    contactor off within at most 100ms!
    With the normal loop we have an ADC integration time of 250ms, so we
    can't possibly react fast enough.
    To fix this we have a "fast loop" that is used in state C.
    The fast loop measures with an integration time of TBDms and it only
    measures the voltage between CP/PE.
    The voltage between PP/PE is ignored (the cable obviously can't be
    changed out while a car is charging, so it is save to ignore the
    PP/PE voltage while in state C.
    [ads1118.c]
2020-12-16 Use 32SPS for fast mode instead of 128SPS
    This is still fast enough to satisfy the 100ms defined in the IEC61851
    standard, but there is much less noise in the ADC data
    [ads1118.c]
2020-12-16 Use 300 ohm as lower range for state C
2020-12-16 Only turn ignore the LED pin if logging is enabled
    We run the rest of the code normally to make sure that
    everything behaves exactly the same if logging is enabled
2020-12-16 Add support for start/stop charging aut set/get autostart
2020-12-17 Fix button direction
2020-12-17 Remove motor direction and duty cycle
    Too low-level for a user
    [communication.c, communication.h]
2020-12-23 We use resistance divider of 910 ohm on EVSE
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2021-01-15 Add calibration for different duty cycles in state C
2021-01-27 Make sure 2700ohm and 880ohm calibration is not overwritten by initial memset
2021-01-27 Add error states (corresponds to LED blink codes)
    [communication.c, communication.h]
2021-02-01 Remove Zoe Test
    The test was done before the calibration with different charging
    currents. With the calibration the resistance is always around 880 Ohm,
    as expected.
2021-02-16 Update default cal_min/max_voltage
    We take the average min/max voltage of the first 100 calibrated EVSEs.
    This default value should now be as good as it gets.
2021-02-16 Allow connected car during initial calibration
    we just need to make sure to not activate the contactor
2021-02-16 Make sure initial value for contactor check is correct
    [config.h]
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2021-03-08 Check error state first
    [communication.c]
2021-05-07 Make sure managed current doesn't go back and forth between 32000 and 0 in unmanaged state
    [evse.c]
2021-05-10 add version 1.5
    [evse.kicad_pcb, evse.sch]
2021-05-10 Remove EVSE lock switch support for now
    This is not used by WARP charger and EVSE hardware 1.x will not be sold
    to any third party, we will start third party sales with 2.x
    [evse.c]
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2021-05-28 Add special handling for ID.3 behavior
    When an ID.3 is connected to the WARP charger and the duty cycle is already
    below 100% (the wallbox is ready) but the contactor is not yet activated, the
    ID.3 somtimes generates a spike in the resistance that we measure when it
    engages the resistor to apply 880 ohm between CP/PE. We have not seen this in
    other cars, we assume this is some kind of capacitive effect. To make sure
    that we don't cancel the charging here, we increase the "STATE A" threshold and
    the "infinite resistance" threshold for this scenario.
    [ads1118.c, iec61851.c]
2021-05-28 Save EVSE configuration in EEPROM to make it persistant after restart
    Currently we only save the managed configuration
2021-07-06 Add evse_get_cp_duty_cycle and evse_set_cp_duty_cycle function
    This fixes accidental erroneous initialization of cp_duty_cycle
    [ads1118.c, communication.c, config.h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]
2021-07-06 Use the correct magic number for managed configuration
    [evse.c]
2021-07-06 Ignore glitches in contactor check
    [config.h]
2021-10-12 Calculate time since pwm change correctly
    [communication.c]
2021-10-12 Only update pwm time if we change from or to 100%
2021-10-13 Add ChargeTime parameter to low level state getter
2021-10-15 Add GetAllDataX API
    For internal use in WARP Charger only
    [communication.c, communication.h]
2021-10-20 Set charging time to 0 if in managed mode and max current is changed to 0
2021-10-25 Update KiCad link
    https://www.kicad.org/blog/2021/10/Avoid-links-to-former-kicad-domain/
2022-03-04 Add charging slot support
    This is made to be as close to the EVSE V2 implementation as possible
    to make sure that it behaves the same.
2022-03-07 Add missing button_pressed value in AllData function
    [communication.h]
2022-03-07 Make sure button charging slots allowes charging again
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2022-06-07 * Make sure to never start charging when key switch is turned off
    * Increase ID.3 mode wait time hysteresis time from 500ms to 2500ms
    * Make sure LED turns on until standby for every state change
2022-07-29 Make sure charging starts again when autostart is active
    and stop button was pressed while car was not charging
2022-07-29 Improve CP/PE resistance calculation
    Make sure there can't be over-/underflow
2022-09-13 Add minimum time of 30s between error state E/F and next activation of contactor
    [iec61851.c]
2023-06-15 Move contactor check to bricklib2/warp
    [communication.c, evse.c, iec61851.c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]
2023-06-16 Add blink led indicator code 2001-2010 for custom error code
    with 1-10 "blink amount"
    [communication.c, config.h, led.c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]
2023-07-06 Fix read of stored startup value of boost mode
    [config.h, evse.c]
2023-07-07 User has to disconnect first for error state EF, but not for D
    [iec61851.c]
2023-08-21 Add CONTACTOR_PIN define for bricklib2 compatibility
    Some changes of the WARP3 branch did leak into the bricklib2.
    For now we just use both defines here (RELAY and CONTACTOR).
    Later when we merge the WARP3 branch the RELAY define will be removed.
    [config_evse.h]
2024-01-10 Every error state results in a charger state
    [communication.c]
2024-02-02 move to kicad 7
    [evse.kicad_pcb, evse.kicad_sch, evse.sch]
2024-06-27 Force 16A PWM in specific state for better CP/PE measurement
2024-09-05 Make sure charging time is zeroed when car does not wake up
2024-09-19 Make sure charging time is always started when IEC61851 state changes to C
2024-11-18 Fix whitespace
    Normally the Bricklet firmwares use tabs. Lots of spaces have
    crept into the EVSE firmware, convert it back to tabs.
    [ads1118.c, ads1118.h, communication.c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]
2024-12-03 Remove "charging time" and add "car stopped charging"
2024-12-05 Set external charging slot to enabled with 32A on first boot of 2.1.13
2025-09-21 Always define LOGGING_UARTBB for CoMCU-Bricklets
    otherwise the compiler sees a rogue "printf" because of
    #ifdefs and throws bogus warnings
2025-10-02 Fix -Wextra warnings and add new warning flags introduced in EVSE V2
    [ads1118.c, communication.c, evse.c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]
2026-07-24 Clear slot if no ev is connected and clear on disconnect is set
2026-07-24 Set slot to default value, if defaults change
2026-07-24 Use correct charging slot (off-by-2 to default)
    [communication.c]
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

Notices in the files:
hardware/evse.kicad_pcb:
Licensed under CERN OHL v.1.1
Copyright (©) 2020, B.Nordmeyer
